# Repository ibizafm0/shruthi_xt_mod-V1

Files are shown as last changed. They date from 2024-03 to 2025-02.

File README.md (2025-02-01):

# Shruthi XT mod (updated February 2, 2025)

This modification is a clone of the popular Shruthi-1, a digital/analog hybrid MIDI monosynth. The author of the project, Emilie Gillette [Mutable Instruments](https://pichenettes.github.io/mutable-instruments-documentation/), has posted all the resources for this device in the repository of his profile [github.com](https://github.com/pichenettes). Documentation for the original project is available here [Mutable Instruments: NON Eurorack project](https://pichenettes.github.io/mutable-instruments-diy-archive/)

This modification is a completely changed design of the main board, as well as additional filter boards, which in turn also changed their design and board size.

Original filter boards are not suitable for this project. The entire design has been reduced and redesigned for SMD type electronic components, including all chips including the atmega644 processor.

This synthesizer design is still in development, but the main board and the smr4mk2 filter have already been tested for errors and functionality. In the future, the boards may be modified, but to a lesser extent. There may be minor changes in the location of connectors or some parts.

Main board dimensions 207.5 mm x 110 mm. Dimensions of the filter board are 55 mm x 85 mm.
For this project there was a need to redraw the electrical circuit for routing. In addition, a preliminary case and top panel have been created.
All listed files are posted as is in the repository resource files.

In the process of debugging the main board and the filter board, version numbering of changes was used. At the time of publication, the main board has an index of 0.5, the sm4mk2 filter board has an index of 0.3

## [Shruthi XT mod rev 0.5](https://github.com/ibizafm0/shruthi_xt_mod)  
Rev 0.5 main PCB
Front
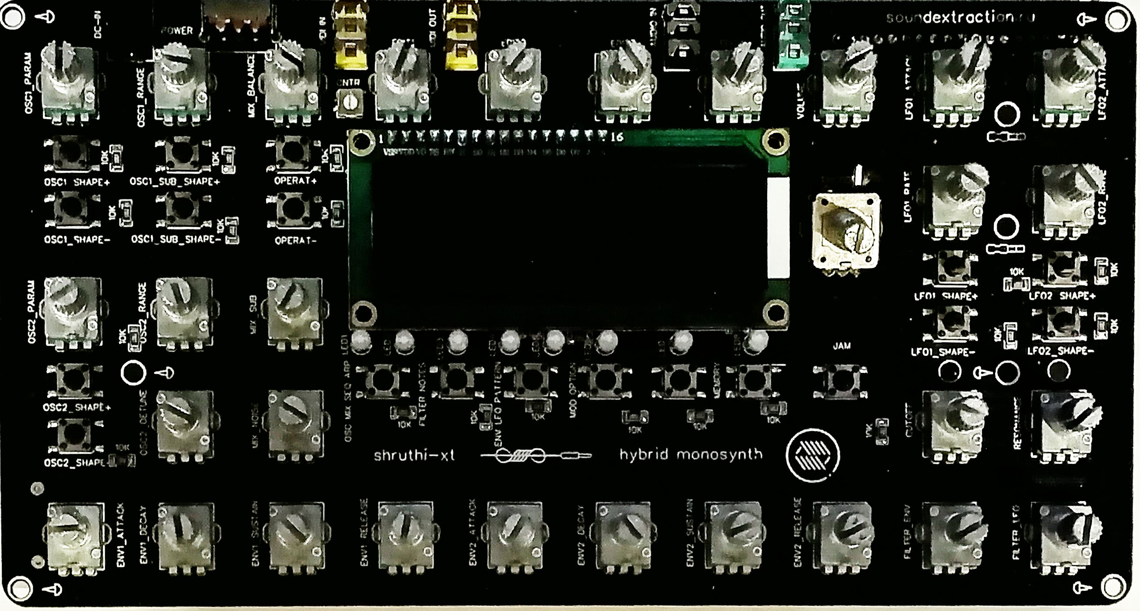
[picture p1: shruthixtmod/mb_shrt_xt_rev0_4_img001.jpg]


Rev 0.5 main PCB
Rear
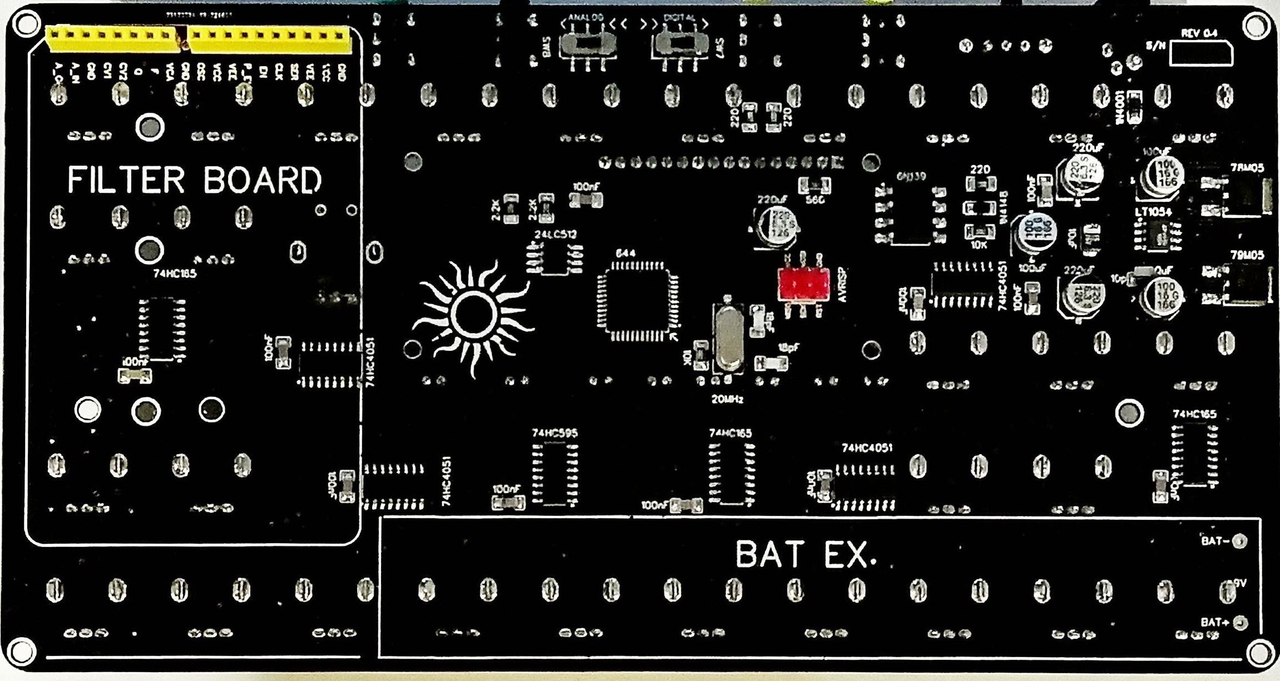
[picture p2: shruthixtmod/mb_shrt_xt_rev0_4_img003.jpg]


Rev 0.3 filter PCB SMR4MK2
Front
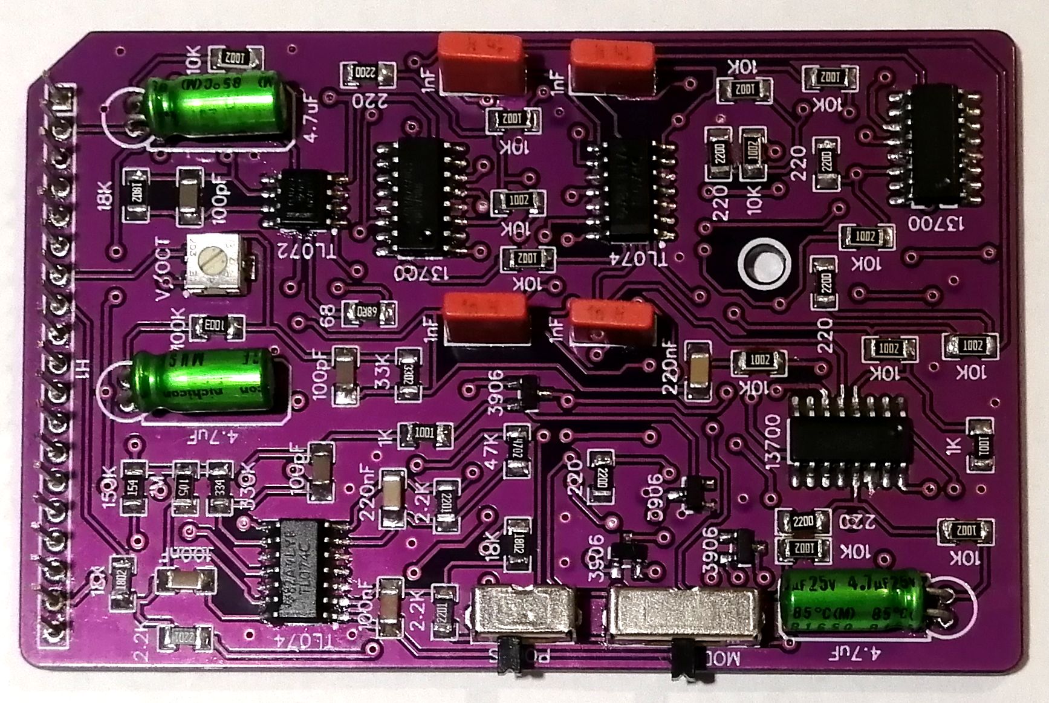
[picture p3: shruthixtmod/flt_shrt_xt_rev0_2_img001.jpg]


Rev 0.3 filter PCB SMR4MK2
Rear
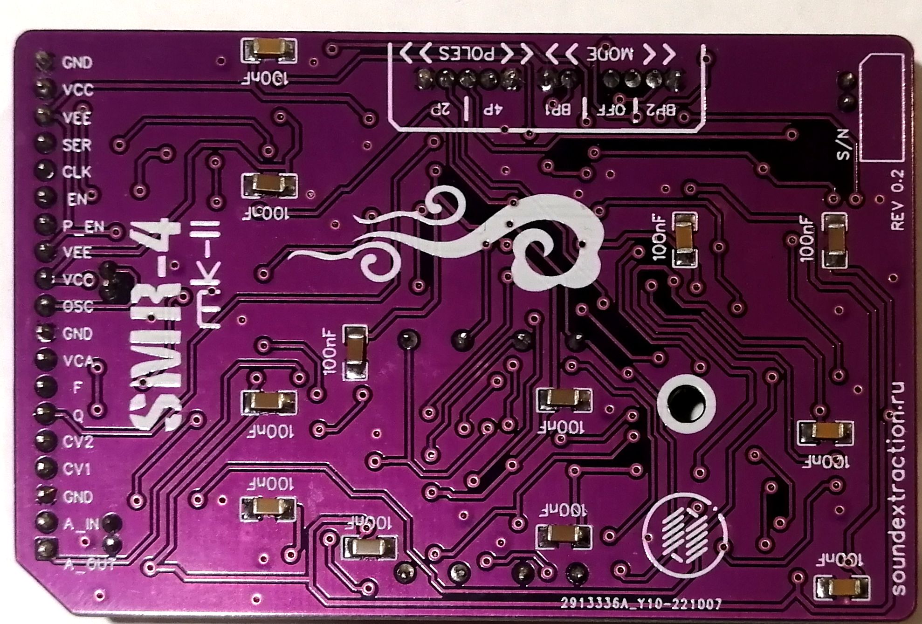
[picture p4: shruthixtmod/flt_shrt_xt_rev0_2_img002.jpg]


Additional photos of a working prototype
========

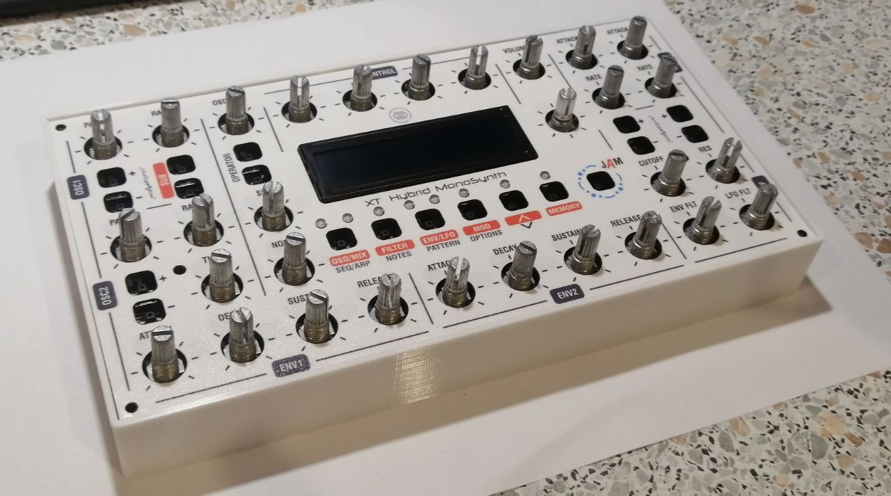
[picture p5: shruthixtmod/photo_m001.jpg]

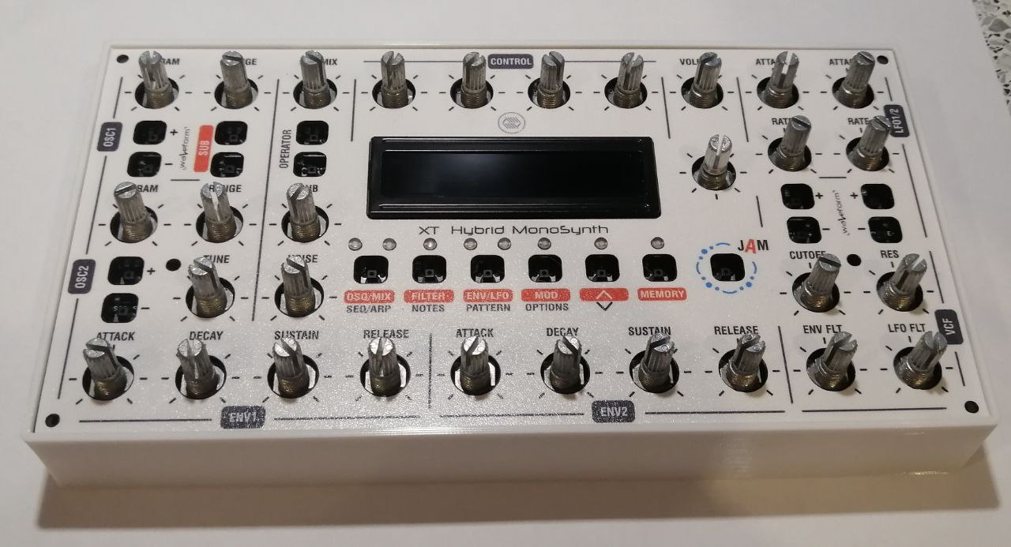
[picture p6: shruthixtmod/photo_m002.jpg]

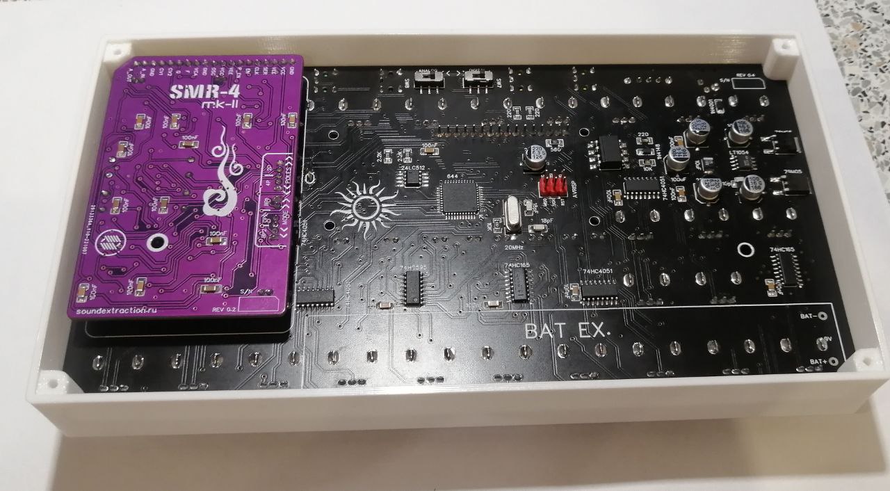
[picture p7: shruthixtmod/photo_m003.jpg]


Description of changes
========

- The main pcb board of the device has the maximum possible minimum size, at which all controls will be conveniently located without interfering with each other when adjusting parameters. Knobs for potentiometers can have a maximum diameter of 10 mm.
- All input power circuits of the device, previously located on the filter pcb boards, are now routed to the main pcb board. Thus, the cost of the filter, as well as the complete device with several filters, is significantly reduced.
- Since the filter circuits now have fewer components and the main pcb board has been reduced in size, the filter pcb boards have been brought down to the basic standard of 55mm x 85mm, similar in size to a standard plastic card (yes, I want the filter be the size of a plastic card = ))
- The seat for the filter pcb board is designed for a larger pcb board size, in case you need to design some kind of extremely cool filter that would not fit into a standard 55 mm x 85 mm space. It is permissible to design pcb boards measuring 55 mm x 105 mm into the footprint.
- In the author's original version, the output sound volume can be adjusted in two ways: digital adjustment and analog adjustment. In order to switch sound control options, it was necessary to use a soldering iron and solder. In the same modification project, to switch adjustment options, it is enough to switch a pair of switches on the back of the main pcb board.
- All filters in the original design have settings for the output sound and filtering using changeover jumpers. In the modified version, linear sliding switches are installed instead of jumpers.

Updates February 2, 2025
========

- Diode assemblies have been added to the MIDI input circuit to use TRS MIDI Type A and Type B formats.
- Main board has an index of 0.5, the sm4mk2 filter board has an index of 0.3
- In the current version, a 5.5 mm x 2.1 mm power port is installed on the main pcb board to power the device.
- Installing ferrite beads, in case of using an OLED display, to prevent interference.
- Added pins for in-circuit firmware of the 24lc512 memory chip.

Upcoming of changes
========

- The 24-step encoders used in the modified version, for some strange circumstances, had different switching directions from batch to batch, and therefore it will be necessary to add additional contacts to change the polarity of the encoder adjustment.
- Need to consider adding spring mounting holes to accommodate the battery compartment. Portable use is an interesting idea, why not.
- It is necessary to consider the possibility of reducing the thickness of the synthesizer structure.

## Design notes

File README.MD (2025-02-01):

# Shruthi XT МОД (обновлено 02.02.2025)/  [ENGLISH VERSION](https://github.com/ibizafm0/shruthi_xt_mod/blob/main/README.md)

Эта модификация является клоном популярного Shruthi-1, цифро-аналогового гибридного моносинтезатора MIDI. Автор проекта Эмили Джилетт [Mutable Instruments](https://pichenettes.github.io/mutable-instruments-documentation/) разместил все ресурсы по этому устройству в репозитории своего профиля [github.com](https://github.com/pichenettes). Документация исходного проекта доступна здесь [Mutable Instruments: проект NON Eurorack](https://pichenettes.github.io/mutable-instruments-diy-archive/)

Данная модификация представляет собой полностью изменённую конструкцию основной платы, а также дополнительных плат фильтров, которые в свою очередь также изменили свой дизайн и размер платы.

Оригинальные фильтрующие платы не подходят для этого проекта. Вся конструкция была уменьшена и переработана для электронных компонентов типа SMD, включая все микросхемы и процессор atmega644.

Данная конструкция синтезатора еще находится в разработке, но основная плата и фильтр smr4mk2 уже проверены на наличие ошибок и работоспособность. В дальнейшем платы возможно будут доработаны, но в меньшей степени. Возможны незначительные изменения в расположении разъемов или некоторых деталей.

Размеры основной платы 207,5 x 110 мм. Размеры фильтр платы 55 мм х 85 мм.
Для этого проекта возникла необходимость перечертить электрическую схему для трассировки. Кроме того, изготовлен предварительный корпус и верхняя панель.
Все перечисленные файлы публикуются в файлах ресурсов репозитория в том виде, в каком они есть.

В процессе отладки основной платы и платы фильтров использовалась нумерация версий изменений. Обновление основной платы имеет индекс 0.5, плата фильтра sm4mk2 имеет индекс 0.3.

## [Shruthi XT mod rev 0.5](https://github.com/ibizafm0/shruthi_xt_mod)  
Ревизия 0.5 основной платы
Вид спереди


Ревизия 0.5 основной платы
Вид сзади


Ревизия 0.3 Плата фильтр SMR4MK2
Вид спереди 


Ревизия 0.3 Плата фильтр SMR4MK2
Вид сзади


Дополнительные фотографии рабочего прототипа
========





Описание изменений
========

- Основная печатная плата устройства имеет максимально возможный минимальный размер, при котором все элементы управления будут удобно расположены, не мешая друг другу при настройке параметров. Ручки потенциометров могут иметь максимальный диаметр 10 мм.
- Все входные силовые цепи устройства, ранее расположенные на платах фильтров, теперь выведены на главную плату. Таким образом, стоимость фильтра, а также всего устройства с несколькими фильтрами существенно снижается.
- Поскольку в схемах фильтров теперь меньше компонентов, а основная печатная плата уменьшена в размерах, размеры печатных плат фильтров уменьшены до базового стандарта 55 x 85 мм, что соответствует размеру стандартной пластиковой карты (да, я хочу фильтр размером с пластиковую карту = ))
- Гнездо для печатной платы фильтра предназначено для печатной платы большего размера на случай, если вам понадобится сконструировать какой-то очень крутой фильтр, который не поместится в стандартное пространство 55 x 85 мм. В посадочное место допускается проектировать печатные платы размером 55х105 мм.
- В оригинальной авторской версии громкость выходного звука можно регулировать двумя способами: цифровой регулировкой и аналоговой регулировкой. Для того, чтобы переключить варианты управления звуком, пришлось воспользоваться паяльником и припоем. В этом же проекте модификации для переключения вариантов регулировки достаточно переключить пару переключателей на обратной стороне основной печатной платы.
- Все фильтры в оригинальном исполнении имеют настройки вывода звука и фильтрацию с помощью переключающих перемычек. В модифицированной версии вместо перемычек установлены линейные ползунковые переключатели.

Обновления от 02.02.2025
========

- В схему миди входа добавлены диодные сборки, для использования обоих форматов TRS midi type A и type B
- Ревизия основной платы имеет индекс 0.5, плата фильтра sm4mk2 имеет индекс 0.3.
- Установлен порт питания размером 5,5 мм х 2,1 мм. взамен 4,0 мм x 1,7 мм
- Добавлены посадочные места для установки ферритов SMD, в случае использования OLED-дисплея, для предотвращения помех.
- Добавлены дополнительные пины для внутрисхемной прошивки микросхемы памяти 24lc512.

Предстоящие изменеия
========

- 24-шаговые энкодеры, использованные в модифицированной версии, по каким-то странным обстоятельствам имели разное направление переключения от партии к партии, в связи с чем необходимо будет добавлять дополнительные контакты на основную плату, для изменения полярности регулировки энкодера.
- Рассмотреть возможность уменьшить толщину конструкции синтезатора.
- Необходимо рассмотреть возможность добавления отверстий для крепления пружин? для размещения батарейного отсека. Портативное использование — интересная идея, почему бы и нет.

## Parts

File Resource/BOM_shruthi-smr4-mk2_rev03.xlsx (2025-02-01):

Description | Package | Quantity | Value | Value
R1 | 330K | 1 | Resistor | SMD 1206
R2 | 150K | 1 | Resistor | SMD 1206
R3 | 100K | 1 | Resistor | SMD 1206
R4 | 47K | 1 | Resistor | SMD 1206
R5 | 33K | 1 | Resistor | SMD 1206
R6 | 1M | 1 | Resistor | SMD 1206
R7,R8,R9 | 18K | 3 | Resistor | SMD 1206
R22,R23,R24 | 2.2K | 3 | Resistor | SMD 1206
R25,R26 | 1K | 2 | Resistor | SMD 1206
R27,R28,R29,R30,R31,R32 | 220 | 6 | Resistor | SMD 1206
R33 | 68 | 1 | Resistor | SMD 1206
R34,R10,R11,R12,R13,R14,R15,R16,R17,R18,R19,R20,R21 | 10K | 13 | Resistor | SMD 1206
R37 | 20K | 1 | Trimmer | SMD-3314J
C2,C3,C4,C5 | 1nF*60V Film | 4 | Film WIMA cap | L7.2-W2.5-H6.5-P5.0
C10,C11,C12,C13,C14,C15,C16,C17,C18,C19,C20,C21,C8,C9 | 100nF | 14 | Ceramic cap | SMD 1206
C6,C7 | 220nF | 2 | Ceramic cap | SMD 1206
C27,C28,C29 | 100pF | 3 | Ceramic cap | SMD 1206
C24,C26,C25 | 4.7uF*50V NP | 3 | Electrolytic cap | 5x11mm
Q1,Q2,Q3,Q6 | 2N3906 | 4 | PNP | SOT-23-3
U1,U2,U3 | LM13700 | 3 | OTA | SOIC-16
U4,U5 | TL074 | 2 | quad op-amp | SOIC-14
U6 | TL072 | 1 | dual op-amp | SOIC-8
SW1 | Switches | 1 | Linear switch | SS-13D07
SW2 | Switches | 1 | Linear switch | SS-12D07
H1 | Pin header | 1 | 2 pin | HDR-TH-19P-P2.54

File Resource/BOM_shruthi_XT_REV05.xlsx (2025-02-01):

Description | Package | Quantity | Value | Footprint
R1,R2 | 2.2K | 2 | Resistor | SMD 1206
R3, R10, R39, R40, R41, R42, R43, R44, R45, R46, R47, R48, R49, R50, R51, R52, R53, R54, R55, R56, R57, R58, R59, R60, R61, R62, R63, R64, R65 | 10K | 29 | Resistor | SMD 1206
R38 | 560 | 1 | Resistor | SMD 1206
R4, R5, R6 | 220 | 3 | Resistor | SMD 1206
C1,C20 | 18pF | 2 | Ceramic cap | SMD 1206
C2, C7, C8, C9, C10, C12, C13, C14, C15, C24, C25, C3, C4, C5, C6 | 100nF | 15 | Ceramic cap | SMD 1206
C18 | 10pF | 1 | Ceramic cap | SMD 1206
C17 | 10uF*16V | 1 | Tantalum cap | SMD-L3.5-W2.8
C11,C22,C23 | 220uF*16V | 3 | Electrolytic cap | SMD-BD6.3-L6.6-W6.6
C16, C19, C21 | 100uF*16V | 3 | Electrolytic cap | SMD-BD6.3-L6.6-W6.6
L1,L2 | 470uH | 2 | Inductor | NLV32T-012J-EF
D1 | 1N4001 | 1 | Diode | SMD 1206
D2 | 1N4148 | 1 | Diode | SMD 1206
D3, D4 | BAT54S | 2 | schottky diodes | SOT-23-3
U1 | Atmega644P | 1 | MC | TQFP-44
U2, U3, U4, U5 | 74HC4051 | 4 | 1:8 Multiplexer | SOIC-16
U7, U8, U9 | 74HC165 | 3 | PISO reg | SOIC-16
U12 | 6N139 | 1 | Optocoupler | SMD-8
U6 | 24LC512 | 1 | Flash mem | SOIC-8
U13 | LT1054 | 1 | DC DC Converter | SOIC-8
U16 | 74HC595 | 1 | POSI reg | SOIC-16
U10 | 79M05 | 1 | -5V Vreg | TO-252-2
U15 | 78M05 | 1 | +5V Vreg | TO-252-2
R37 | 50K | 1 | Trimmer | SMD-3314J
R7, R8, R9, R11, R12, R13, R14, R15, R16, R17, R18, R19, R20, R21, R22, R23, R24, R25, R26, R27, R28, R29, R30, R31, R32, R33, R34, R35, R36 | B10K | 29 | Linear pot | RK097N
LCD1 | LCD1602 | 1 | LCD | LMB162ADC
X1 | 20MHz | 1 | Quartz | HC-49S-L11.4-W4.8
LED1, LED2, LED3, LED4, LED5, LED6, LED7, LED8 | 3mm LED | 8 | LEDs (flat top)
ENCODER | EC11 | 1 | ENCODER | EC11E1820402
SW7,SW8 | Switches | 2 | Linear switch | SS-3235S
SW1, SW2, SW3, SW4, SW5, SW9, SW12, SW13, SW14, SW15, SW17, SW18, SW19, SW20, SW21, SW22, SW23, SW24, SW25 | Switches | 19 | tactile switch | SMD-4P-L6-W6
DC1 | DC-044 | 1 | DC 5,5/2,5
J1, J2, J3, j4 | PJ-313D | 4 | AUDIO JACK | PJ-3135
FLASH | Pin header | 1 | 2 pin | HDR-TH-2P-P2.54
AVRISP | Pin header | 1 | 6 pin | HDR-TH-6P-P2.54
U11 | Fem header | 1 | 10 pin | HDR-TH-10P-P2.54
U14 | Fem header | 1 | 8 pin | HDR-TH-8P-P2.54

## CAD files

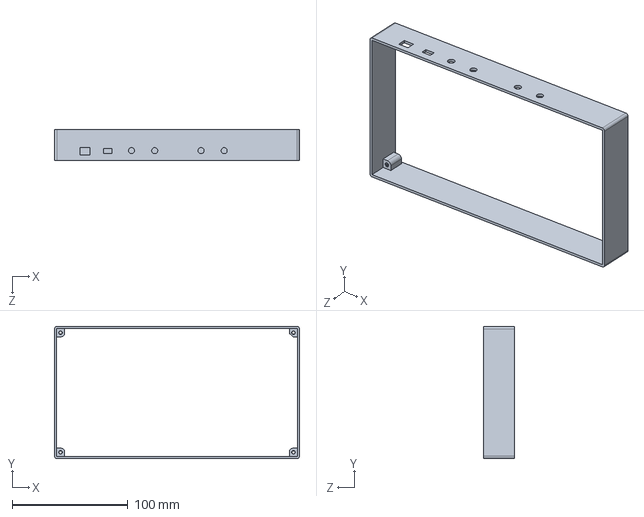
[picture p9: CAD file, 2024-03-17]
Resource/case3d_solidworks.SLDPRT
211.5 x 114.0 x 27.0 mm

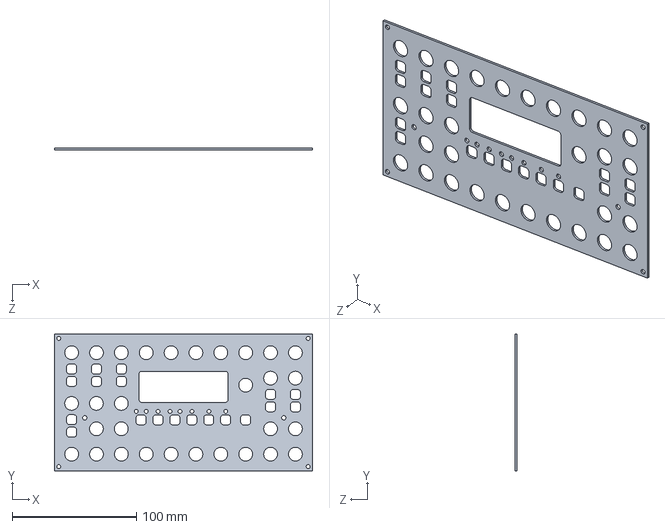
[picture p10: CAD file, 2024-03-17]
Resource/panel3d_solidworks.SLDPRT
207.5 x 110.0 x 1.50 mm

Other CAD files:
Resource/panel3d_15mm.STL

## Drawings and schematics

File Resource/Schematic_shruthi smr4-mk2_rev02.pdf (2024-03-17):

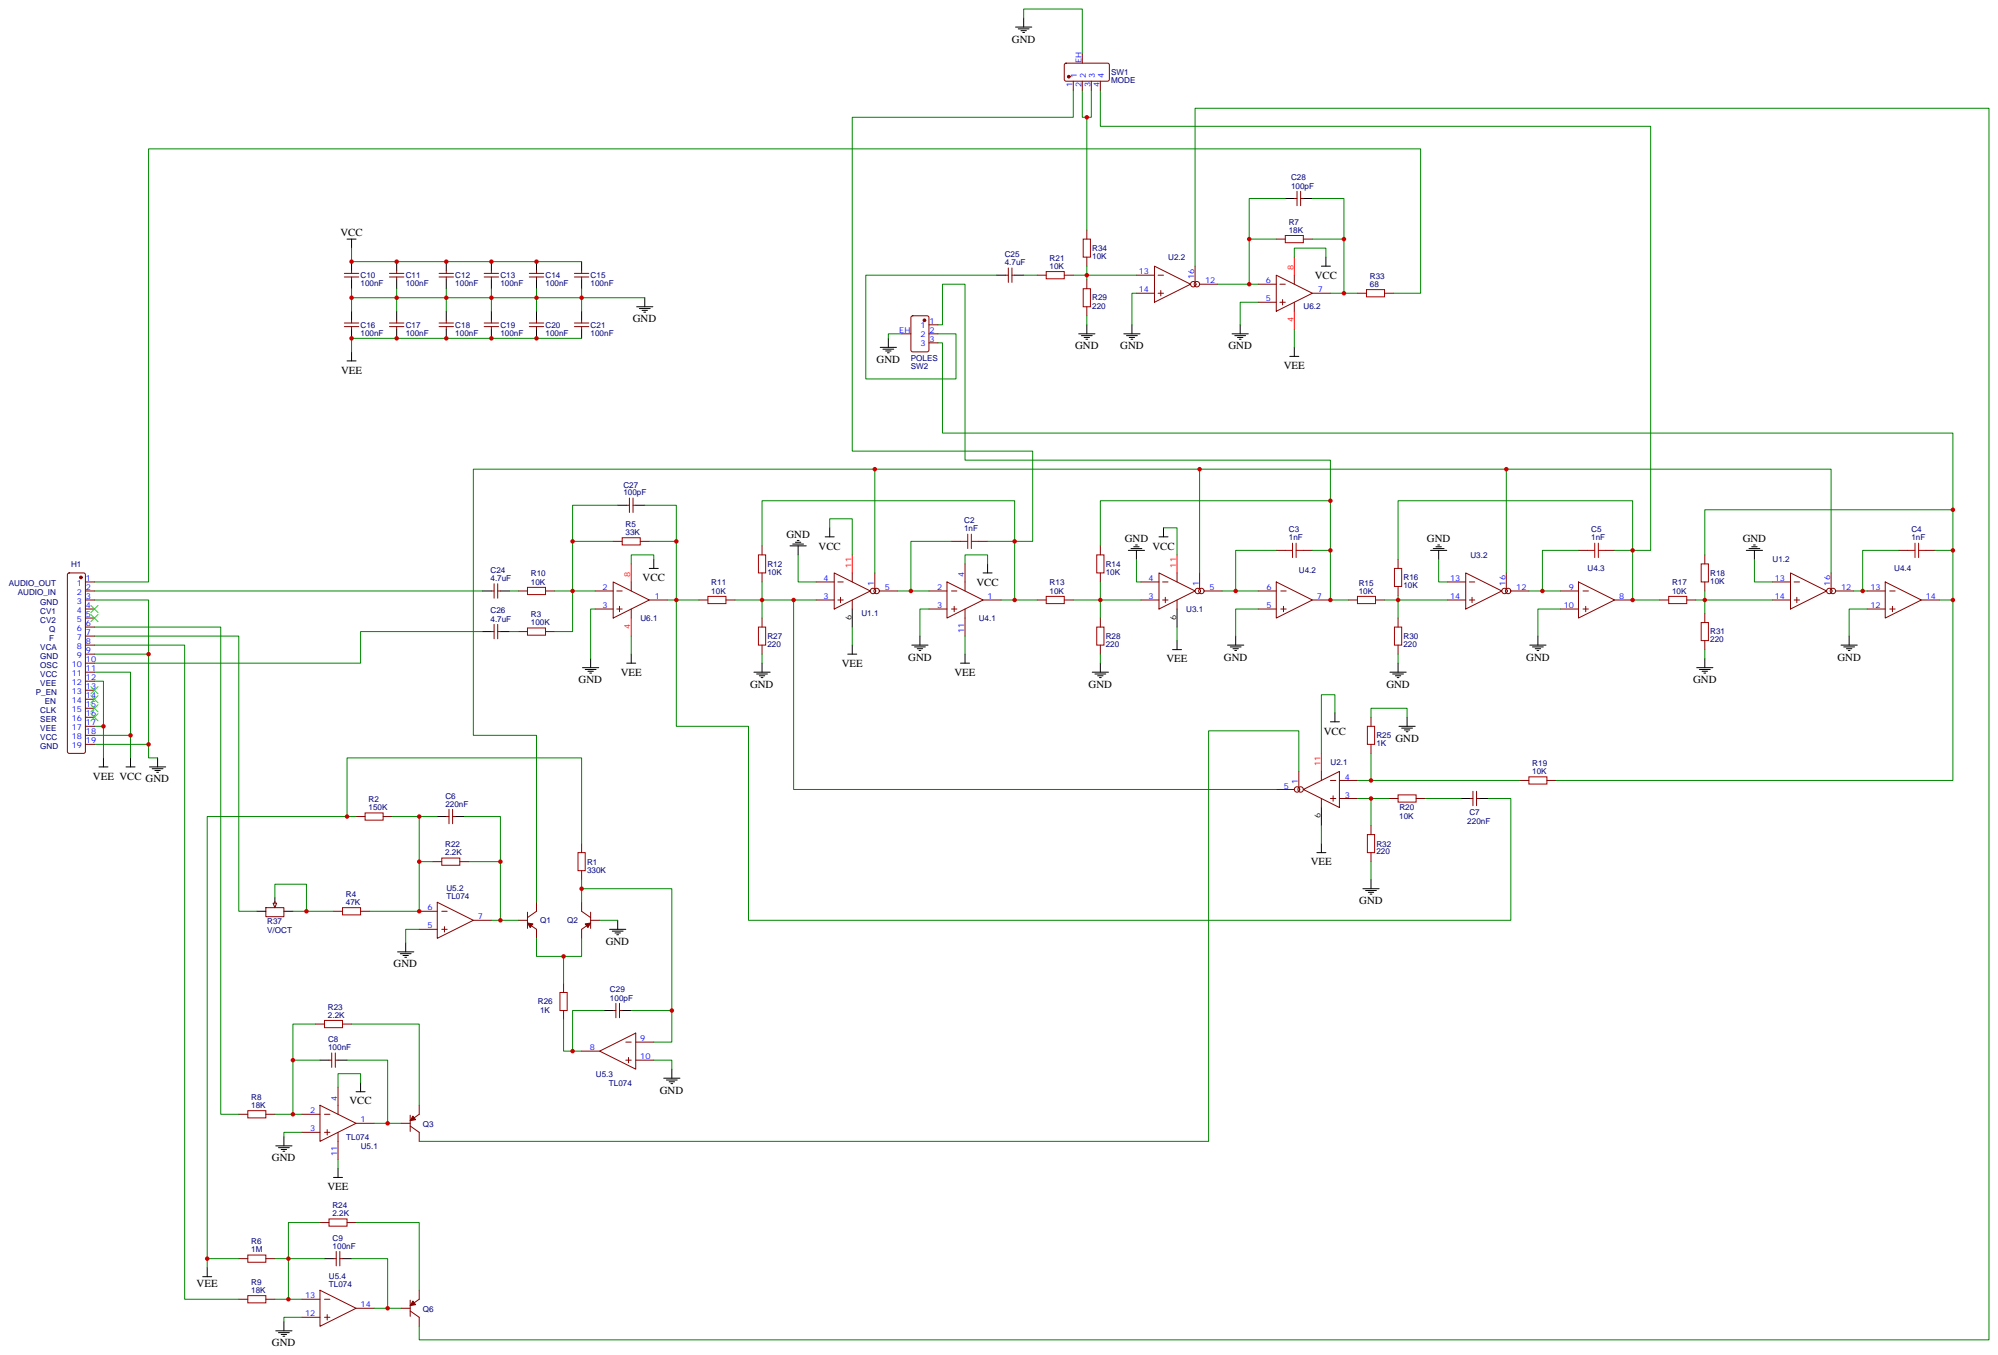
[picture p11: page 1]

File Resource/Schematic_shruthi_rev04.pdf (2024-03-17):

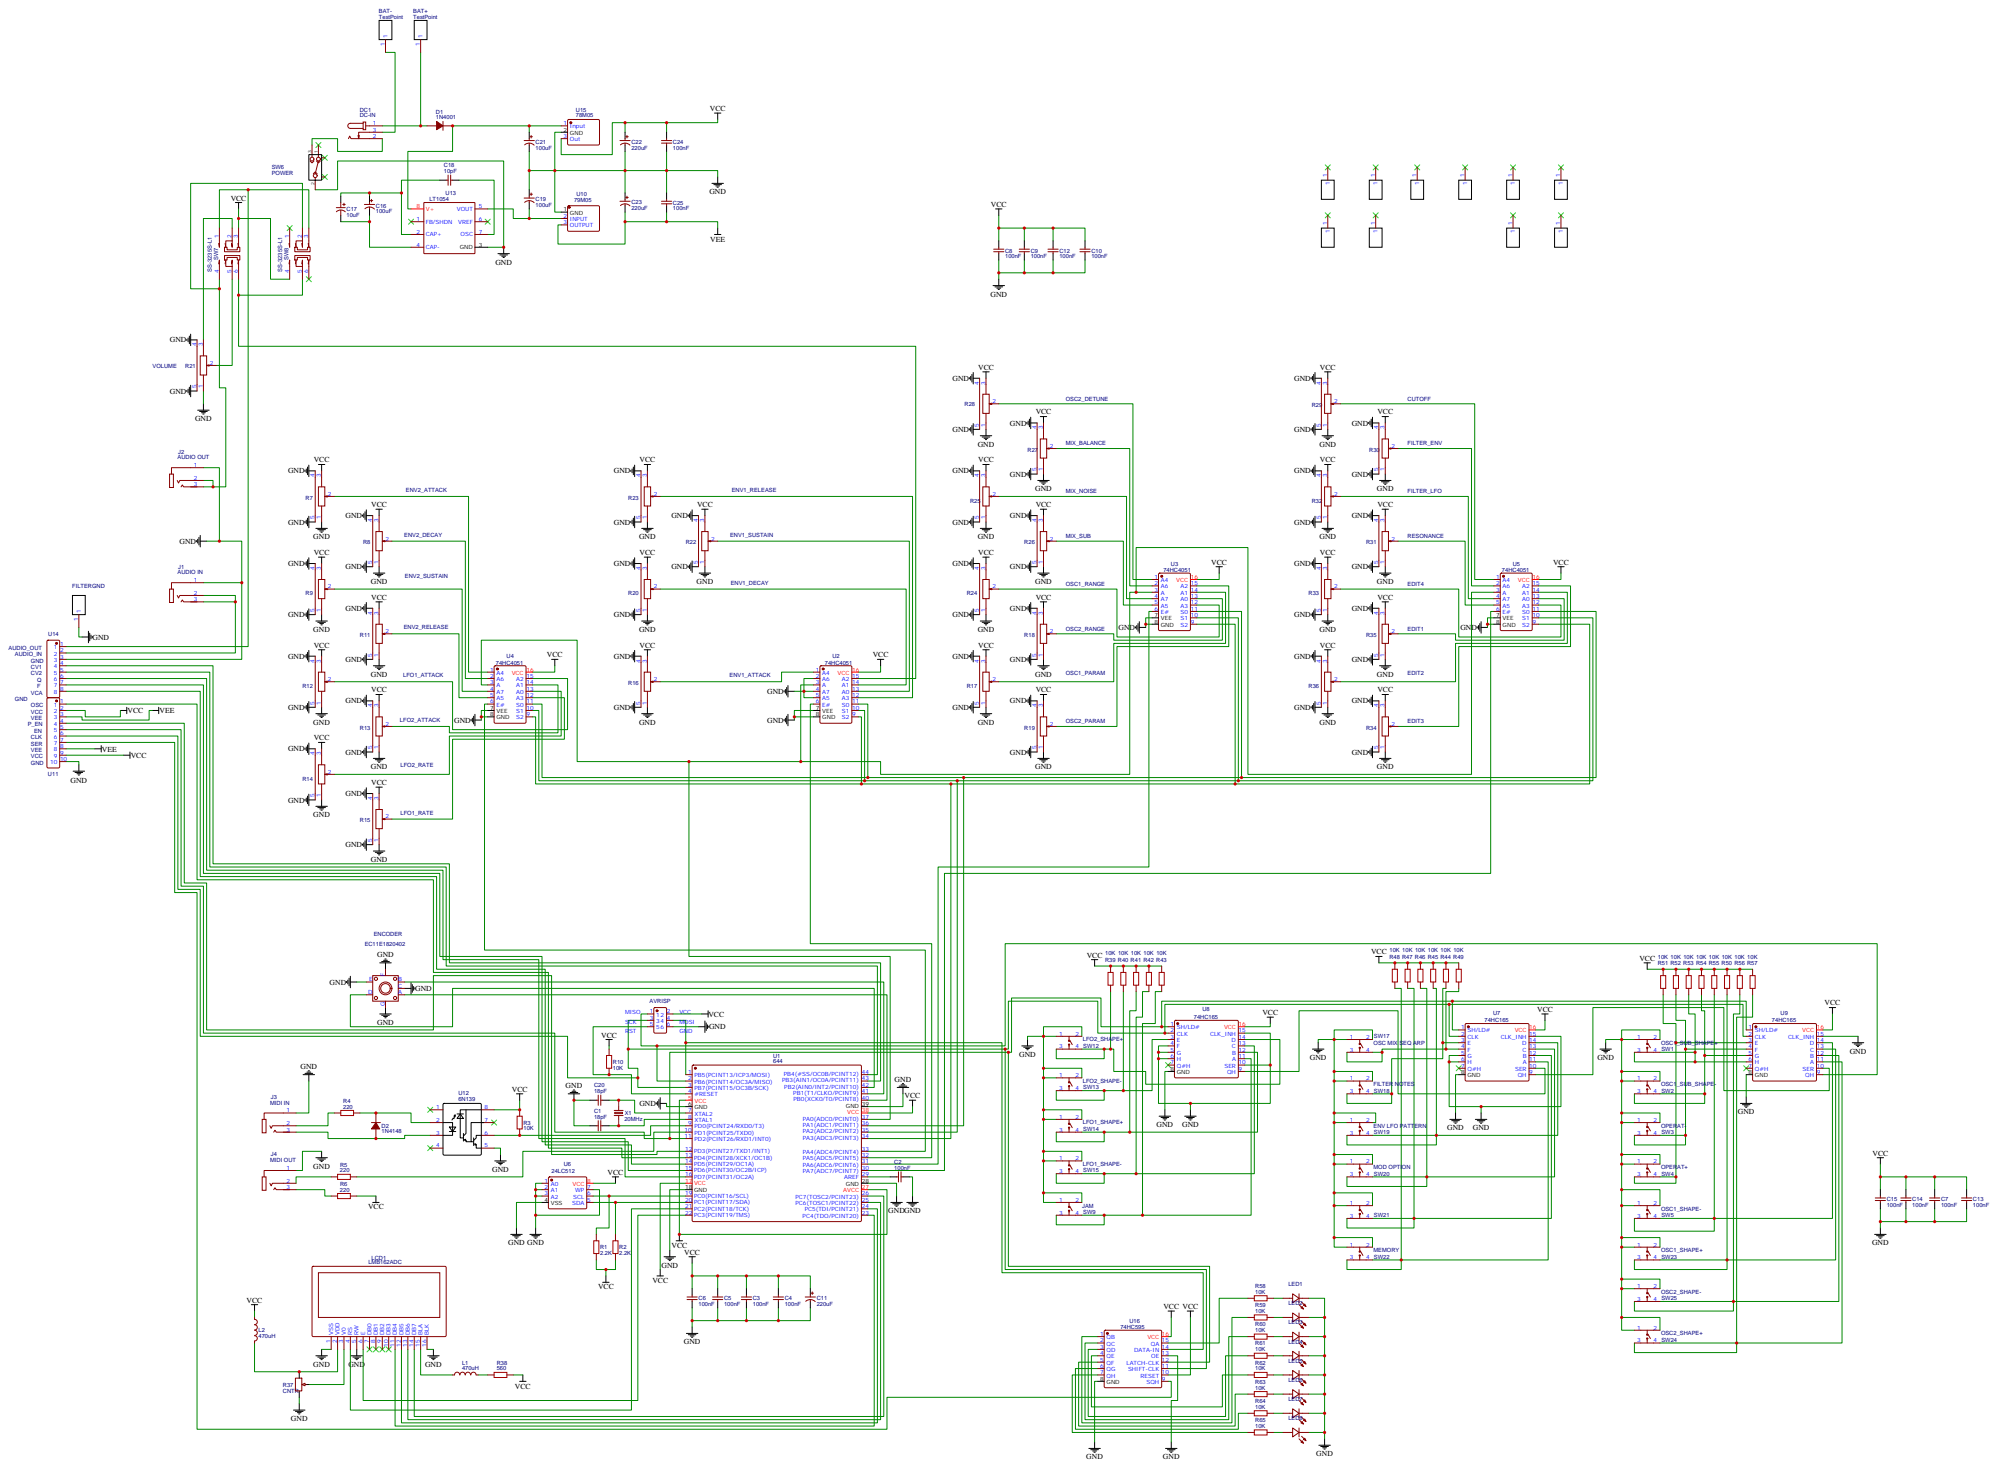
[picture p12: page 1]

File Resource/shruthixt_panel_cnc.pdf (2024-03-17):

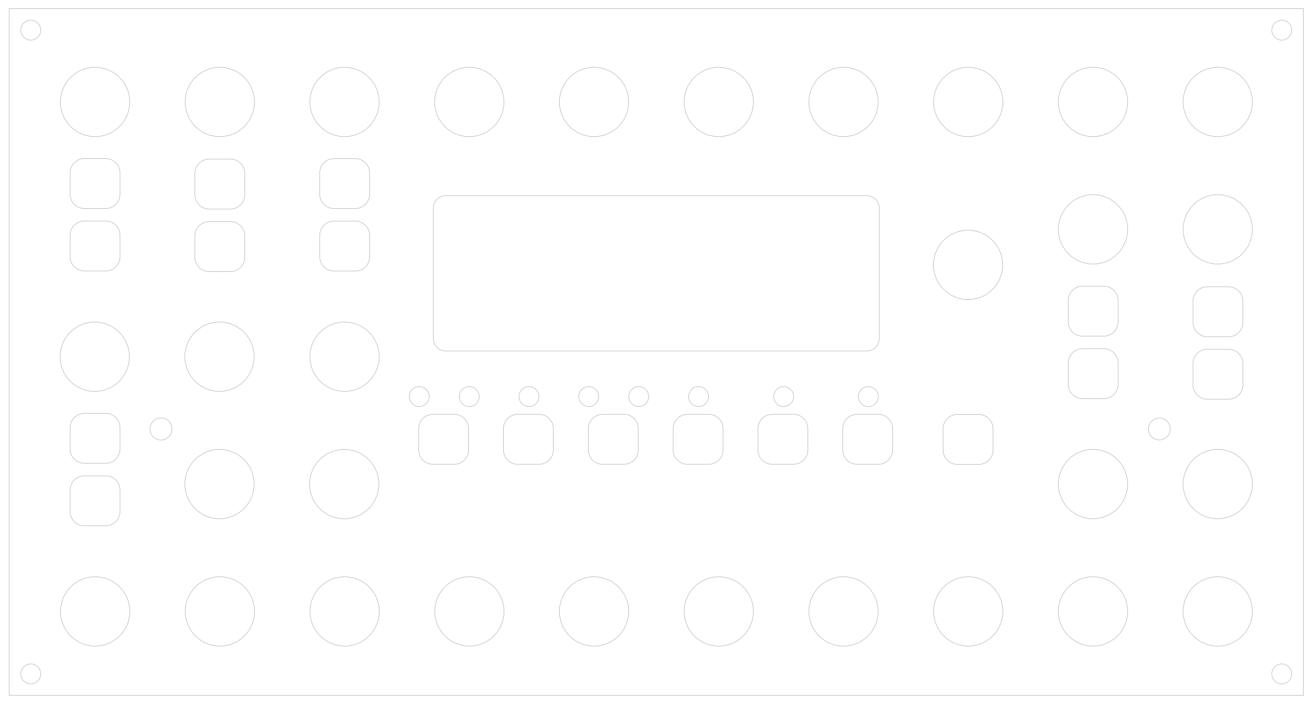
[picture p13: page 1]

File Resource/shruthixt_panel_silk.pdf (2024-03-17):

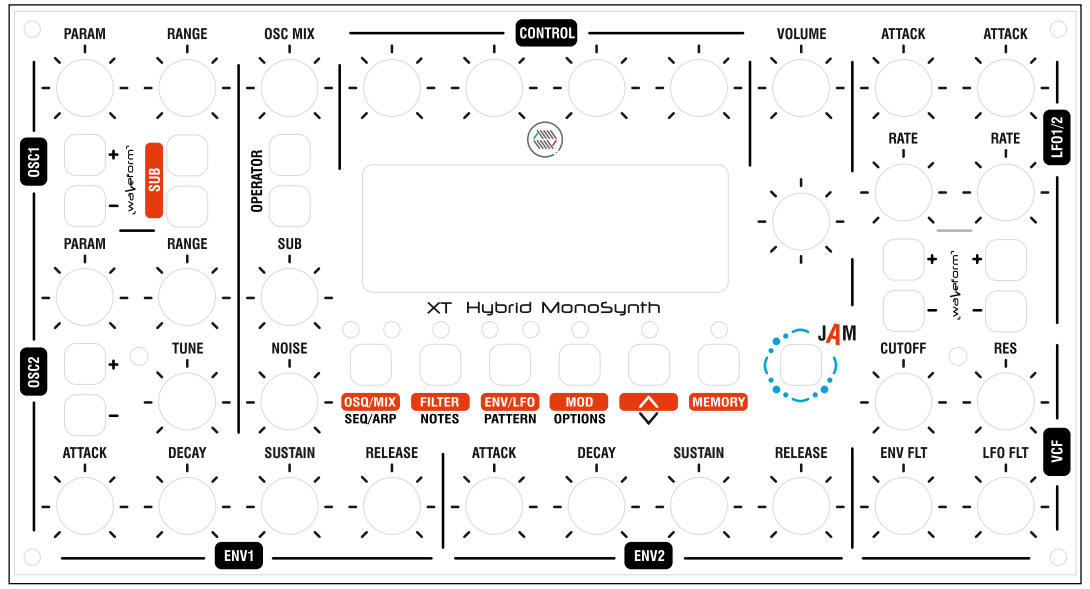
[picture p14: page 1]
SUSTAIN
